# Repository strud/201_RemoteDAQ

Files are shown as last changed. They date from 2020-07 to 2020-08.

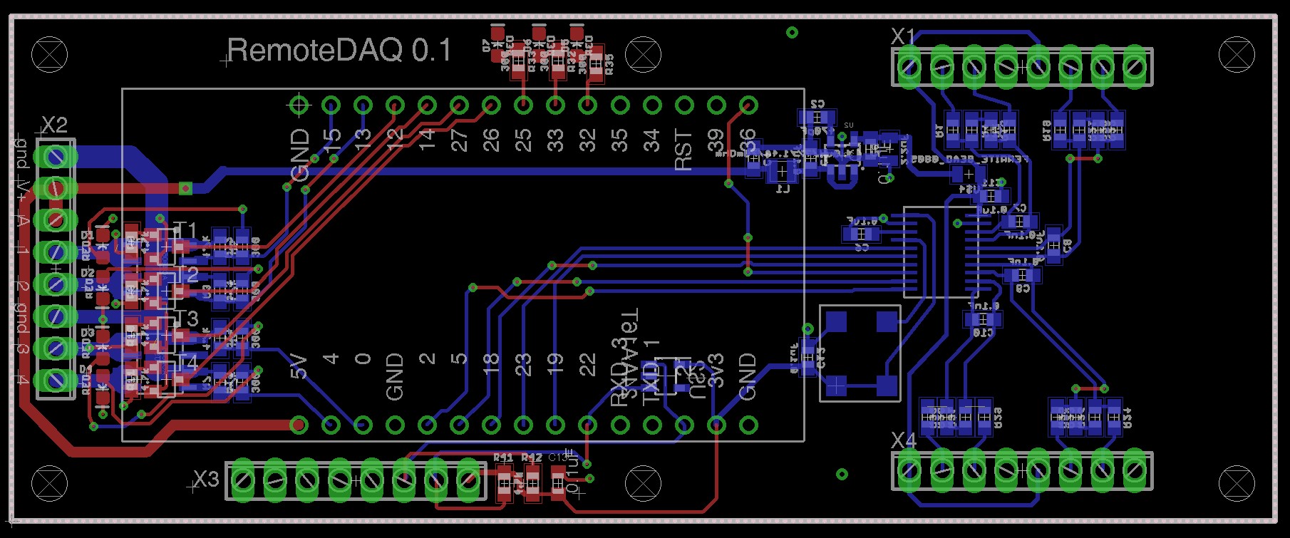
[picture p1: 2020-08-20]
040_Images/RemoteDAQ_board_no_fill.jpg

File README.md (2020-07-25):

# 201_RemoteDAQ
DAQ module with wireless connectivity and local storage

Objectives
1. High resolution low noise analog input capture at rates of at least 5kHz
2. Suitable to take signal inputs of strain gauges/load cells and thermocouples directly without additional pre-amplification
3. At least 4 channels
4. Configuration, live view and download over wireless interface(s)
5. Low channel count (>= 4) of digital outputs, 5A capacity with self protection (ie against short cct)
6. Output channels to have continuity test inputs
7. Internall logging capability at full acquisition rate for at least 30s duration
8. logged file retrieval to be over wireless link &/or to removable SD card

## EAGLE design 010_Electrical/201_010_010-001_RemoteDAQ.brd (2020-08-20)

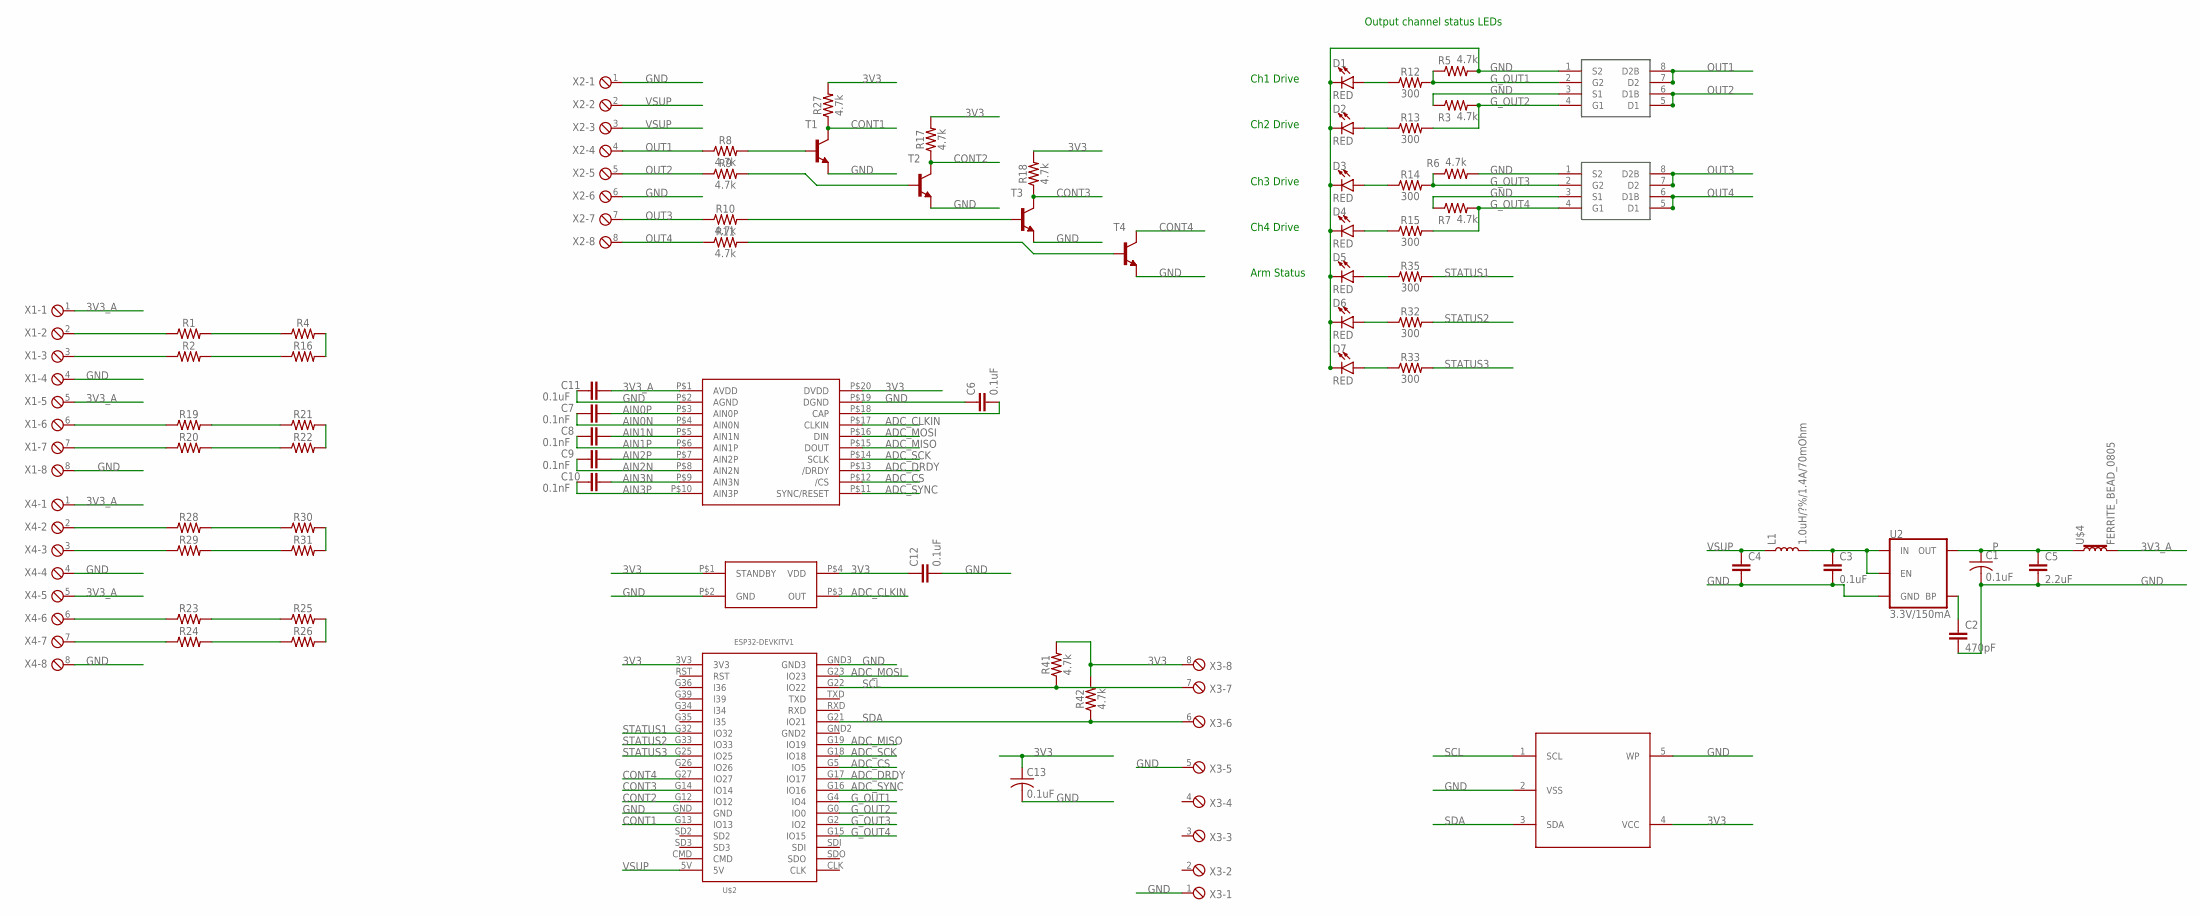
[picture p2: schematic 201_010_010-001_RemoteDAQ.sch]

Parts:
C1, C13: 0.1uF; C0603K
C2: 470pF; 0603
C3, C6, C11, C12: 0.1uF; 0603
C4: CAP-0603; 0603
C5: 2.2uF; 0805
C7, C8, C9, C10: 0.1nF; 0603
D1, D2, D3, D4, D5, D6, D7: RED; LED-0603
L1: 1.0uH/?%/1.4A/70mOhm; 0805-WIDE
R1, R2, R4, R16, R19, R20, R21, R22, R23, R24, R25, R26, R28, R29, R30, R31: 0603
R3, R5, R6, R7, R8, R9, R10, R11, R17, R18, R27, R41, R42: 4.7k; 0603
R12, R13, R14, R15, R32, R33, R35: 300; 0603
T1, T2, T3, T4: BC849-NPN-SOT23-BEC; SOT23-BEC
U2: 3.3V/150mA; SOT23-5
U$1: ADS131M04; TSSOP-20
U$2: ESP32DEVKITV1; ESP32-DEVKITV1
U$3, U$5: AO4806; SO08
U$4: FERRITE_BEAD_0805; 0805
U$6: DSC1033; 7X5_PP
U$7: 24AA16T; SOT23-5L
X1, X2, X3, X4: MPT8; 8POL254

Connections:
3V3: C12.1, C13.1, R17.2, R18.2, R27.2, R41.2, R42.2, U$1.P$20 (DVDD), U$2.3V3, U$6.P$1 (STANDBY), U$6.P$4 (VDD), U$7.4 (VCC), X3.8
3V3_A: C11.2, U$1.P$1 (AVDD), U$4.2, X1.1, X1.5, X4.1, X4.5
ADC_CLKIN: U$1.P$17 (CLKIN), U$6.P$3 (OUT)
ADC_CS: U$1.P$12 (/CS), U$2.G5 (IO5)
ADC_DRDY: U$1.P$13 (/DRDY), U$2.G17 (IO17)
ADC_MISO: U$1.P$15 (DOUT), U$2.G19 (IO19)
ADC_MOSI: U$1.P$16 (DIN), U$2.G23 (IO23)
ADC_SCK: U$1.P$14 (SCLK), U$2.G18 (IO18)
ADC_SYNC: U$1.P$11 (SYNC/RESET), U$2.G16 (IO16)
AIN0N: C7.1, R2.2, R16.1, U$1.P$4 (AIN0N)
AIN0P: C7.2, R1.2, R4.1, U$1.P$3 (AIN0P)
AIN1N: C8.2, R20.2, R22.1, U$1.P$5 (AIN1N)
AIN1P: C8.1, R19.2, R21.1, U$1.P$6 (AIN1P)
AIN2N: C9.1, R24.2, R26.1, U$1.P$8 (AIN2N)
AIN2P: C9.2, R23.2, R25.1, U$1.P$7 (AIN2P)
AIN3N: C10.2, R29.2, R31.1, U$1.P$9 (AIN3N)
AIN3P: C10.1, R28.2, R30.1, U$1.P$10 (AIN3P)
CONT1: R27.1, T1.C, U$2.G13 (IO13)
CONT2: R17.1, T2.C, U$2.G12 (IO12)
CONT3: R18.1, T3.C, U$2.G14 (IO14)
CONT4: T4.C, U$2.G27 (IO27)
GND: C1.2, C2.2, C3.2, C4.2, C5.2, C6.1, C11.1, C12.2, C13.2, D1.C, D2.C, D3.C, D4.C, D5.C, D6.C, D7.C, R3.1, R5.2, R6.2, R7.1, T1.E, T2.E, T3.E, T4.E, U2.2 (GND), U$1.P$2 (AGND), U$1.P$19 (DGND), U$2.GND, U$2.GND3, U$3.1 (S2), U$3.3 (S1), U$5.1 (S2), U$5.3 (S1), U$6.P$2 (GND), U$7.2 (VSS), U$7.5 (WP), X1.4, X1.8, X2.1, X2.6, X3.1, X3.5, X4.4, X4.8
G_OUT1: R5.1, R12.2, U$2.G4 (IO4), U$3.2 (G2)
G_OUT2: R3.2, R13.2, U$2.G0 (IO0), U$3.4 (G1)
G_OUT3: R6.1, R14.2, U$2.G2 (IO2), U$5.2 (G2)
G_OUT4: R7.2, R15.2, U$2.G15 (IO15), U$5.4 (G1)
unnamed: C2.1, U2.4 (BP)
unnamed: C3.1, L1.2, U2.1 (IN), U2.3 (EN)
unnamed: R8.2, T1.B
unnamed: R9.2, T2.B
unnamed: R1.1, X1.2
unnamed: R10.2, T3.B
unnamed: R11.2, T4.B
unnamed: D1.A, R12.1
unnamed: D2.A, R13.1
unnamed: R2.1, X1.3
unnamed: R19.1, X1.6
unnamed: D3.A, R14.1
unnamed: D4.A, R15.1
unnamed: C6.2, U$1.P$18 (CAP)
unnamed: R20.1, X1.7
unnamed: R4.2, R16.2
unnamed: R21.2, R22.2
unnamed: R28.1, X4.2
unnamed: R29.1, X4.3
unnamed: R25.2, R26.2
unnamed: R23.1, X4.6
unnamed: D5.A, R35.1
unnamed: R24.1, X4.7
unnamed: R30.2, R31.2
unnamed: D6.A, R32.1
unnamed: D7.A, R33.1
OUT1: R8.1, U$3.7 (D2), U$3.8 (D2B), X2.4
OUT2: R9.1, U$3.5 (D1), U$3.6 (D1B), X2.5
OUT3: R10.1, U$5.7 (D2), U$5.8 (D2B), X2.7
OUT4: R11.1, U$5.5 (D1), U$5.6 (D1B), X2.8
P: C1.1, C5.1, U2.5 (OUT), U$4.1
SCL: R41.1, U$2.G22 (IO22), U$7.1 (SCL), X3.7
SDA: R42.1, U$2.G21 (IO21), U$7.3 (SDA), X3.6
STATUS1: R35.2, U$2.G32 (IO32)
STATUS2: R32.2, U$2.G33 (IO33)
STATUS3: R33.2, U$2.G25 (IO25)
VSUP: C4.1, L1.1, U$2.5V, X2.2, X2.3

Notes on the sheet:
Output channel status LEDs
Ch1 Drive
Ch2 Drive
Ch3 Drive
Ch4 Drive
Arm Status

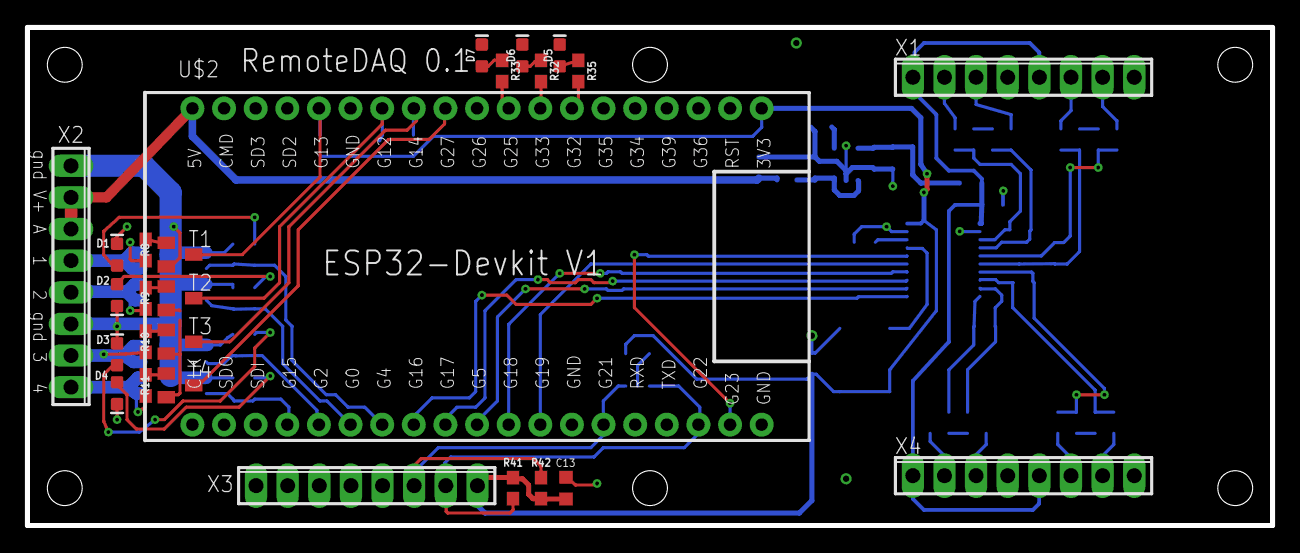
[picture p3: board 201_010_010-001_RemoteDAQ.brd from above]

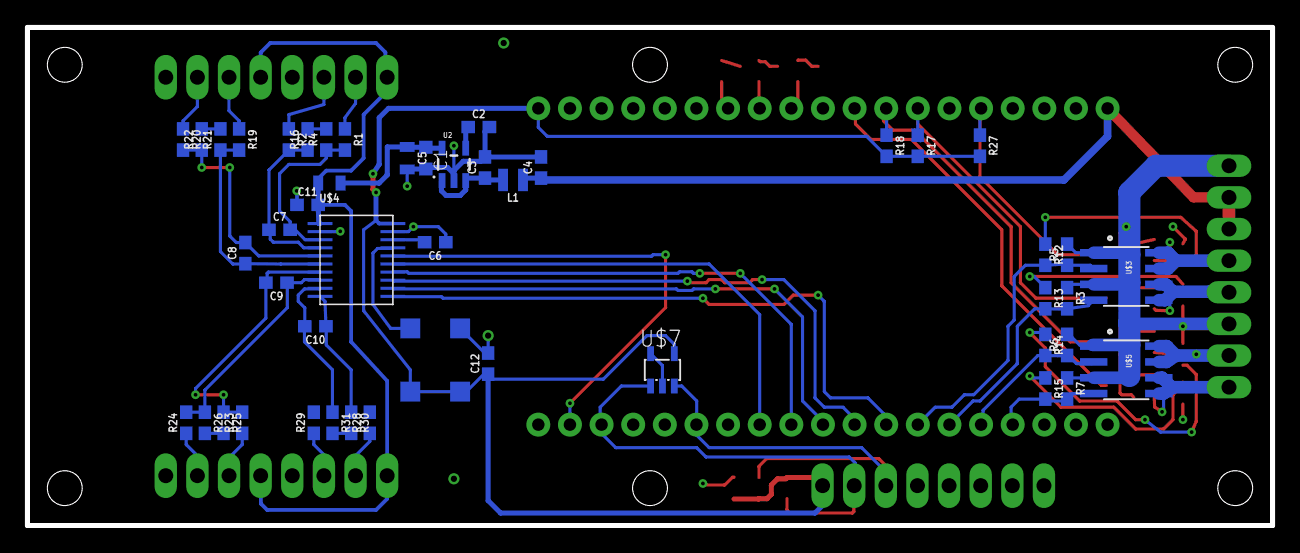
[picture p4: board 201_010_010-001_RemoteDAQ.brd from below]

Board: 2 copper layers, 100.0 x 40.0 mm, 73 parts (47 on the bottom side), 63 nets.

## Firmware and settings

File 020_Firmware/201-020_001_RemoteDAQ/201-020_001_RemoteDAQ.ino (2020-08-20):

/* Revision history
0.1 Initial version - ported from RocTrak project 
*/
#include <SPIFFS.h>
#include <SimpleCLI.h>
#include <FuGPS.h>
#include <Arduino.h>
#include <HardwareSerial.h>

#include <analogWrite.h>
#include <WiFi.h>
#include "Microchip_PAC193x.h"
#include <Wire.h>

#include "ads131m0x.h"
#include "hal.h"

// #defines

#define hw_ver            1

//-------------------------------------
// DAQ State machine states
#define st_daq_initial    10
#define st_daq_check_status 20
#define st_daq_standby      30

//-------------------------------------
// fileLogger states
#define st_log_initial 10
#define st_log_standby 20
#define st_log_create_file 30
#define st_log_waiting_trigger 40
#define st_log_check_APRS 45
#define st_log_write 50
#define st_log_close_file 60
#define st_log_delete_files 70
#define st_log_error_state  80
int logState, nextLogState;

//--------------------------------------
// Define I/O
/* RemoteDAQ rev0.1
  Designed to work with board 201_010_010-001_RemoteDaq rev0.1
  
*/
//-----------------------------------------------------------
// Pin definitions going around the board 

    //#define SPARE       36  // Connected to GPS Tx 
    //#define SPARE   39
    //#define SPARE   34
    //#define SPARE_  35
    #define STATUS1   32
    #define STATUS2   33
    #define STATUS3   25   
    //#define SPARE    26
    #define Cont4Pin    27   // output ch4 continuity measurement
    #define Cont3Pin    14   // output ch3 continuity measurement
    #define Cont2Pin    12   // output ch2 continuity measurement
    #define Cont1Pin    13   // output ch1 continuity measurement
    #define GOut4Pin    15
    #define GOut3Pin    2  // output ch3 FET gate drive
    #define GOut2Pin    0  // output ch2 FET gate drive
    #define GOut1Pin    4   // output ch1 FET gate drive
    #define ADC_SYNC    16 // 
    #define ADC_DRDY    17 // 
    #define ADC_CS      5 // 
    #define ADC_SCK     18   // 
    #define ADC_MISO    19    //
    #define SDAPin      21
    #define SCLPin      22
    #define ADC_MOSI    23 // 

// forward declarations

void errorCallback(cmd_error* e);
void cmdFileListCallback(cmd* c);
void cmdFileDownloadCallback(cmd* c);
void cmdFileEraseCallback(cmd* c);
void cmdCommandListCallback(cmd* c);
void cmdSystemStatusCallback(cmd* c);
void cmdOutputDriveCallback(cmd* c);
void updateFileSystemParameters(void);

struct FileSystemParamsType {
  unsigned long totalBytes;
  unsigned long usedBytes;
  unsigned long remainingBytes;
  float usedSpace;
  float remainingSpace;
} FileSystemParams;


// CLI objects

// Create CLI Object
SimpleCLI cli;

// Commands
Command cmdFileList;
Command cmdFileDownload;
Command cmdFileErase;
Command cmdParameterList;
Command cmdCommandList;
Command cmdGpsStatus;
Command cmdDtmfSimulate;
Command cmdSystemStatus;
Command cmdOutputDrive;
Command cmdPowerMon;
//----------------------------------------------------------------------------

int value;

//--------------------------------------
// DTMF related vars
unsigned int DtmfVal;
unsigned int DtmfNew;
int          DtmfValArrayFull;
unsigned int DtmfValArray[25];
int          DtmfValCount;
int          DtmfState, DtmfNextState;
unsigned long DtmfTimer;

//--------------------------------------
// Output channel vars
int Cont1, Cont2, Cont3, Cont4;
String sCont1, sCont2, sCont3, sCont4;
int Out1, Out2, Out3, Out4;
String sOut1, sOut2, sOut3, sOut4;
//--------------------------------------
// Generic time related vars
unsigned long TimeDelta;

//--------------------------------------------------------------------------
// Webserver related vars & objects

const char* ssid     = "RocTrak_WAP";    // Replace with your network credentials
const char* password = "123456789";

WiFiServer server(80);  // Set web server port number to 80
//---------------------------------------------------------------------------

String header;          // Variable to store the HTTP request
String strGpsLockState;  //
String strGPSLat;  
String strGpsLong;
String strAltitude;
String strSatellites;
//--------------------------------------------------------------------------
// converts character array 
// to string and returns it 
String convertToString(char* a, int lengthOf) 
{ 
    int i; 
    String s = ""; 
    for (i = 0; i < lengthOf; i++) { 
        s = s + a[i]; 
        if (a[i]==0) break;
    } 
    return s; 
} 
//--------------------------------------------------------------------------
void updateContinuity(void){
if (digitalRead(Cont1Pin)==LOW) {
    sCont1 = "CC";
    Cont1 = 1;
  }
  else {
    sCont1 = "OC";
    Cont1=0;
  }
  if (digitalRead(Cont2Pin)==LOW) {
    sCont2 = "CC";
    Cont2 = 1;
  }
  else {
    sCont2 = "OC";
    Cont2=0;
  }if (digitalRead(Cont3Pin)==LOW) {
    sCont3 = "CC";
    Cont3 = 1;
  }
  else {
    sCont3 = "OC";
    Cont3=0;
  }
  if (digitalRead(Cont4Pin)==LOW) {
    sCont4 = "CC";
    Cont4 = 1;
  }
  else {
    sCont4 = "OC";
    Cont4=0;
  } 
}
  
void updateOutputs(void){

  if (Out1==1) sOut1 = "1";
  else sOut1 = "0";
  if (Out2==1) sOut2 = "1";
  else sOut2 = "0";
  if (Out3==1) sOut3 = "1";
  else sOut3 = "0";
  if (Out4==1) sOut4 = "1";
  else sOut4 = "0";
}

void setup() {
  // put your setup code here, to run once:

  // Setup I/O 
     
  // FET driven Output channels related
  pinMode(GOut1Pin, OUTPUT);
  pinMode(GOut2Pin, OUTPUT);
  pinMode(GOut3Pin, OUTPUT);
  pinMode(GOut4Pin, OUTPUT);
  pinMode(Cont1Pin, INPUT_PULLUP);
  pinMode(Cont2Pin, INPUT_PULLUP);
  pinMode(Cont3Pin, INPUT_PULLUP);
  pinMode(Cont4Pin, INPUT_PULLUP);
  

  // Serial ports  
  Serial.begin(115200);     // Default port with USB converter
  
  // initialise SPIFFs
  if(!SPIFFS.begin(true)){
     Serial.println("An Error has occurred while mounting SPIFFS");
  }
  
  value=0;

  Wire.begin(SDA, SCL, 400000);

  // Define tasks
  TaskHandle_t TaskH_WebServer;
  TaskHandle_t TaskH_FileLogger;
  TaskHandle_t TaskH_DAQ;
    
  //----------------------------------------------------------------------------------------------------------
  // Setup and creation of tasks
  //----------------------------------------------------------------------------------------------------------

  //create WebServer task that will be executed in the Task_WebServer() function, with priority 5 and executed on core 0
  xTaskCreatePinnedToCore(
                    Task_WebServer, // Task function. 
                    "WebServer",  // name of task. 
                    10000,       // Stack size of task 
                    NULL,        // parameter of the task 
                    5,           // priority of the task 
                    &TaskH_WebServer,  // Task handle to keep track of created task 
                    0);          // pin task to core 0 
  delay(500); 
  
  //create FileLogger task that will be executed in the Task_Logger() function, with priority 7 and executed on core 0
  xTaskCreatePinnedToCore(
                    Task_FileLogger,   // Task function. 
                    "FileLogger",     // name of task. 
                    10000,       // Stack size of task 
                    NULL,        // parameter of the task 
                    7,           // priority of the task 
                    &TaskH_FileLogger,  // Task handle to keep track of created task 
                    0);          // pin task to core 0 
  delay(500); 

  //create DAQ task that will be executed in the Task_DAQ() function, with priority 5 and executed on core 1
  xTaskCreatePinnedToCore(
                    Task_DAQ, // Task function. 
                    "DAQ",  // name of task. 
                    10000,       // Stack size of task 
                    NULL,        // parameter of the task 
                    5,           // priority of the task 
                    &TaskH_DAQ,  // Task handle to keep track of created task 
                    1);          // pin task to core 0 
  delay(500); 

  // Turn on interrupts
  interrupts();
  
  //--------------------------------------------------------------
  // Initialise command line interpreter commands

  cmdCommandList = cli.addSingleArgCmd("?", cmdCommandListCallback);
  cmdFileList = cli.addSingleArgCmd("ls", cmdFileListCallback);
  cmdFileDownload = cli.addSingleArgCmd("dl", cmdFileDownloadCallback);
  cmdFileErase = cli.addSingleArgCmd("erase", cmdFileEraseCallback);
  cmdGpsStatus = cli.addSingleArgCmd("gps", cmdGpsStatusCallback);
  cmdDtmfSimulate = cli.addBoundlessCmd("dtmf", cmdDtmfSimulateCallback);
  cmdSystemStatus = cli.addSingleArgCmd("??", cmdSystemStatusCallback);
  cmdOutputDrive = cli.addSingleArgCmd("out", cmdOutputDriveCallback);
  cmdPowerMon = cli.addSingleArgCmd("pwr", cmdPowerMonitorCallback);
  
  cli.setOnError(errorCallback); // Set error Callback

  //--------------------------------------------------------------
  
  //--------------------------------------------------------------
}
//--------------------------------------------------------------------------
void loop() {
  // put your main code here, to run repeatedly:
  /*
  value+=5;
  analogWrite(PTT4Pin, value);
  delay(200);
  if (value>250) value =0;
  */
  updateContinuity();
  updateOutputs();
  
  /*
  digitalWrite(PTT4Pin, LOW);
  delay(500);
  digitalWrite(PTT4Pin, HIGH);
  delay(500);
  Serial.print("I love you dad\t");
  */

  // example code from fuGPS
  // Valid NMEA message
  
  //---------------------------
  if (Serial.available()){
    // basic command interpreter, primarily for SPIFFs functions at this time
    // Read out string from the serial monitor
    String input = Serial.readStringUntil('\n');
    // Parse the user input into the CLI
       cli.parse(input);
    }

    if (cli.errored()) {
        CommandError cmdError = cli.getError();

        Serial.print("ERROR: ");
        Serial.println(cmdError.toString());

        if (cmdError.hasCommand()) {
            Serial.print("Did you mean \"");
            Serial.print(cmdError.getCommand().toString());
            Serial.println("\"?");
        }
    }    

} // end of default loop()

//--------------------------------------------------------------------------
// ISRs
//
//---------------------------------------------------------------------------

  //---------------------------------------------------------------------------
  // DAQ task setup to run on it's own core so as to be free from interruption
  //---------------------------------------------------------------------------
  void Task_DAQ( void * parameter)
  {
  unsigned int daqState;

  daqstate = st_daq_initial;
  
  for(;;){
    // Implementation of state machine used to operate DAQ system
    switch (daqState) {

      case st_daq_initial :
          
                        
          }
      break;

    delayMicroseconds(1);
  }

  
  }
  //---------------------------------------------------------------------------
  // 
  //---------------------------------------------------------------------------
  void Task_WebServer( void * parameter)
  {
    // Connect to Wi-Fi network with SSID and password
    Serial.print("Setting AP (Access Point)…");
    // Remove the password parameter, if you want the AP (Access Point) to be open
    WiFi.softAP(ssid, password);
    IPAddress IP = WiFi.softAPIP();
    Serial.print("AP IP address: ");
    Serial.println(IP);
    server.begin();   
    
    for(;;){
       
       
       WiFiClient client = server.available();   // Listen for incoming clients

  if (client) {                             // If a new client connects,
    Serial.println("New Client.");          // print a message out in the serial port
    String currentLine = "";                // make a String to hold incoming data from the client
    while (client.connected()) {            // loop while the client's connected
      if (client.available()) {             // if there's bytes to read from the client,
        char c = client.read();             // read a byte, then
        Serial.write(c);                    // print it out the serial monitor
        header += c;
        if (c == '\n') {                    // if the byte is a newline character
          // if the current line is blank, you got two newline characters in a row.
          // that's the end of the client HTTP request, so send a response:
          if (currentLine.length() == 0) {
            // HTTP headers always start with a response code (e.g. HTTP/1.1 200 OK)
            // and a content-type so the client knows what's coming, then a blank line:
            client.println("HTTP/1.1 200 OK");
            client.println("Content-type:text/html");
            client.println("Connection: close");
            client.println();
                                
            // Display the HTML web page
            client.println("<!DOCTYPE html><html>");
            client.println("<head><meta name=\"viewport\" content=\"width=device-width, initial-scale=1\">");
            client.println("<link rel=\"icon\" href=\"data:,\">");
            // CSS to style the on/off buttons 
            // Feel free to change the background-color and font-size attributes to fit your preferences
            client.println("<style>html { font-family: Helvetica; display: inline-block; margin: 0px auto; text-align: center;}");
            client.println(".button { background-color: #4CAF50; border: none; color: white; padding: 16px 40px;");
            client.println("text-decoration: none; font-size: 30px; margin: 2px; cursor: pointer;}");
            client.println(".button2 {background-color: #555555;}");
            client.println("table, th, td {  border: 1px solid black;}</style></head>");
            
            // Web Page Heading
            //client.println("<body><h1>ESP32 Web Server</h1>");
            client.println("<body><h1>RocTrak - live status</h1>");
            //  client.println("");
            client.println("<h2>GPS status</h2>");
            client.print("<hr>");
            // Display current state of GPS Lock
            if (fuGPS.hasFix() == true) client.print("<p>GPS lock status : LOCK<br>");
            else client.print("<p>GPS lock status : NO LOCK<br>");
            client.print("# satellites: " + String(fuGPS.Satellites, 4) +"<br>");
            client.print("Altitude (above sea level): " + String(fuGPS.Altitude, 6) + "<br>");
            client.print("Location (dec deg): " + String(fuGPS.Latitude, 6) + ", " + String(fuGPS.Longitude, 6)+ "<br>");            
            client.print("<hr>");
            client.println("<h2>Power Supply</h2>");
            client.println("<table style=\"width:100%\">");
            client.println("<tr><th> </th><th>Supply1</th><th>Supply2</th><th>Supply3</th></tr>");
            client.println("<tr><td>Voltages (mV)</td><td>"+ String(PAC.Voltage[0],0)+"</td><td>"+ String(PAC.Voltage[1],0) + "</td><td>"+ String(PAC.Voltage[2],0) + "</td></tr>");
            client.println("<tr><td>Current (mA)</td><td>"+ String(PAC.Current[0],1)+"</td><td>"+ String(PAC.Current[1],1) + "</td><td>"+ String(PAC.Current[2],1) + "</td></tr>");
            client.println("<tr><td>Power (mW)</td><td>"+ String(PAC.Power[0],2)+"</td><td>"+ String(PAC.Power[1],2) + "</td><td>"+ String(PAC.Power[2],2) + "</td></tr>");
            client.println("</table>");
            client.println("<h2>Outputs</h2>");
            client.println("<table style=\"width:100%\">");
            client.println("<tr><th> </th><th>Ch1</th><th>Ch2</th><th>Ch3</th><th>Ch4</th></tr>");            
            client.println("<tr><td>Continuity</td><td>"+ sCont1 +"</td><td>"+ sCont2 + "</td><td>"+ sCont3 + "</td><td>"+ sCont4 +"</td></tr>");
            client.println("<tr><td>Outputs </td><td>"+ sOut1 +"</td><td>"+ sOut2 + "</td><td>"+ sOut3 + "</td><td>"+ sOut4 +"</td></tr>");
            client.println("</table>");
            client.println("</body></html>");

            
            
            // The HTTP response ends with another blank line
            client.println();
            // Break out of the while loop
            break;
          } else { // if you got a newline, then clear currentLine
            currentLine = "";
          }
        } else if (c != '\r') {  // if you got anything else but a carriage return character,
          currentLine += c;      // add it to the end of the currentLine
        }
      }
    }
    // Clear the header variable
    header = "";
    // Close the connection
    client.stop();
    Serial.println("Client disconnected.");
    Serial.println("");
  }

     
     delay(5);
     //yield();
    }
   
  }
  

  //------------------------------------------------------------------------------
  // Task_FileLogger : state machine to manage logging of flight variables and 
  // measurements to file
  //------------------------------------------------------------------------------
  void Task_FileLogger( void * parameter)
  {
  // logger writes a single file line in ascii format, once per second.
  // format
  // time (ms)  (from free running counter)
  // time (HMS) (from GPS time)
  // #satellites
  // fix quality
  // accuracy (m)
  // lattitude  (decimal degrees)
  // longitude  (decimal degrees)
  // altitude (m)
  // supply voltage 1 to 3
  // supply current 1 to 3
  // continuity 1 to 4
  // output state 1 to 4
  // DTMF arm status
  // DTMF command

  unsigned long loggerTimer;
  String logEntry;
  String tempString;
  String fileName;
  char tempCharArray[80];
  int i;

  logState = st_log_initial;
  nextLogState = st_log_initial;
  File logFile;

  for(;;){

    switch (logState) {

      case st_log_initial :
          // Check there is enough space to log something, update global FS parameters with result
          updateFileSystemParameters();
          if (FileSystemParams.remainingBytes > 300000){
            logState = st_log_standby;
            Serial.println("->st_log_standby");
          }
          else {
            // need to make some space, for now just bum out
            logState = st_log_error_state;
            Serial.println("not enough remaining space: " + String(FileSystemParams.remainingBytes));
            Serial.println("->st_log_error_state");
            
          }
      break;
      
      case st_log_standby :
        // wait for GPS lock AND APRS rapid transmission rate
        if ((fuGPS.hasFix())&&(myAPRS.enableRapidPackets==1)){
          // create file name from date and time, mdhms (month+day+hour+minute+seconds all 2 digit strings)
          fileName = "/log_";
          // extract time from GPS, 
          myAPRS.setTime(fuGPS.Months, fuGPS.Days, fuGPS.Hours, fuGPS.Minutes, fuGPS.Seconds);
          fileName += convertToString(myAPRS.mdhmsTime, sizeof(myAPRS.mdhmsTime));
          fileName += ".txt";
          Serial.println(fileName);
          logState = st_log_create_file;
          Serial.println("->st_log_create_file");
          
        }
      
      
      break;
      
      case st_log_create_file :
          logFile = SPIFFS.open(fileName, FILE_WRITE);      

          if (!logFile) {
            Serial.println("unable to create logfile");  
            logState = st_log_error_state;
            Serial.println("->st_log_error");            
          }
          else {
            logState = st_log_waiting_trigger;
            loggerTimer = millis();
            Serial.println("->st_log_waiting_trigger");   
            // write file header
            logEntry ="time(ms), time(hms),#Satellites, Qual, HDOP,lat, long, alt, speed, Course, v1, v2, v3, I1, I2, I3, cont1, cont2,cont3, cont4, out1, out2, out3, out4, dmf_state, dtmf0, dtmf1, dtmf2, dtmf3";
            logFile.println(logEntry);          
          }
      
      break;
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

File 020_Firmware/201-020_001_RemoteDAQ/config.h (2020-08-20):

#define RADIO_BAND_2M   200
#define RADIO_BAND_70CM 70


#define PARAM_LIMIT_RADIO_2MBAND_FREQ_LOW_LIMIT 137
#define PARAM_LIMIT_RADIO_2MBAND_FREQ_HIGH_LIMIT 147
#define PARAM_LIMIT_RADIO_70CMBAND_FREQ_LOW_LIMIT 420
#define PARAM_LIMIT_RADIO_70CMBAND_FREQ_HIGH_LIMIT 450
#define PARAM_DEFAULT_RADIO_2MBAND_FREQ 145.000
#define PARAM_DEFAULT_RADIO_70CMBAND_FREQ 433.000
#define PARAM_LIMIT_RADIO_TX_DELAY_LOW      50
#define PARAM_LIMIT_RADIO_TX_DELAY_HIGH     250
#define PARAM_DEFAULT_RADIO_TX_DELAY        100
#define PARAM_LIMIT_APRS_SLOW_TX_PERIOD_LOW  15000
#define PARAM_LIMIT_APRS_SLOW_TX_PERIOD_HIGH 60000
#define PARAM_DEFAULT_APRS_SLOW_TX_PERIOD   20000
#define PARAM_LIMIT_APRS_FAST_TX_PERIOD_LOW  2000
#define PARAM_LIMIT_APRS_FAST_TX_PERIOD_HIGH 10000
#define PARAM_DEFAULT_APRS_FAST_TX_PERIOD   5000
#define PARAM_DEFAULT_APRS_CALLSIGN        "ROCTRK"
#define PARAM_LIMIT_APRS_PREAMBLE_BITS_LOW  10
#define PARAM_LIMIT_APRS_PREAMBLE_BITS_HIGH 150
#define PARAM_DEFAULT_APRS_PREAMBLE_BITS    75
#define PARAM_LIMIT_APRS_AUTO_SLOW_PERIOD_LOW 10
#define PARAM_LIMIT_APRS_AUTO_SLOW_PERIOD_HIGH 120
#define PARAM_DEFAULT_APRS_AUTO_SLOW_PERIOD  20
#define PARAM_DEFAULT_APRS_TX_ENABLE         1
#define PARAM_LIMIT_GPS_RATE_LOW             1
#define PARAM_LIMIT_GPS_RATE_HIGH            5
#define PARAM_DEFAULT_GPS_RATE               1
#define PARAM_LIMIT_GPS_MODE_LOW             1
#define PARAM_LIMIT_GPS_MODE_HIGH            10
#define PARAM_DEFAULT_GPS_MODE               1
#define PARAM_LIMIT_LOG_SAVE_INTERVAL_LOW    100
#define PARAM_LIMIT_LOG_SAVE_INTERVAL_HIGH   5000
#define PARAM_DEFAULT_LOG_SAVE_INTERVAL      1000
#define PARAM_DEFAULT_LOG_SAVE_ENABLE        1
#define PARAM_DEFAULT_DTMF_ALLOW_ARM_LATCH   0
#define PARAM_DEFAULT_WIFI_ENABLE            1
#define PARAM_DEFAULT_WIFI_AP_ENABLE         1
#define PARAM_DEFAULT_BLE_ENABLE             0
#define PARAM_DEFAULT_FS_AUTO_DELETE_OLD     1
#define PARAM_DEFAULT_FS_SAVE_PARAMS_TO_FILE 1

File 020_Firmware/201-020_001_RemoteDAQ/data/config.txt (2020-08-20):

Tx_freq, 145.000
Rx_freq, 145.000
Filter, 010
APRS_packet, _Position_Time

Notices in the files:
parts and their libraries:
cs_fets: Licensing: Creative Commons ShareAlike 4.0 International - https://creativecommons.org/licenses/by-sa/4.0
